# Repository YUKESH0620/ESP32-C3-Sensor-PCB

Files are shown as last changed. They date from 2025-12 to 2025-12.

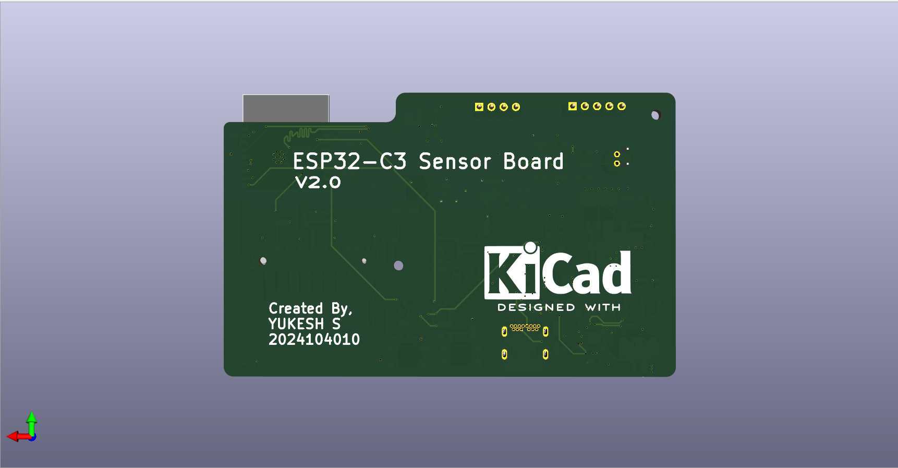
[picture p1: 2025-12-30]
hardware_v0.2_Improved/Kicad_files_v0.2/images_v0.2/PCB_v0.2/Screenshot 2025-12-28 120142.png

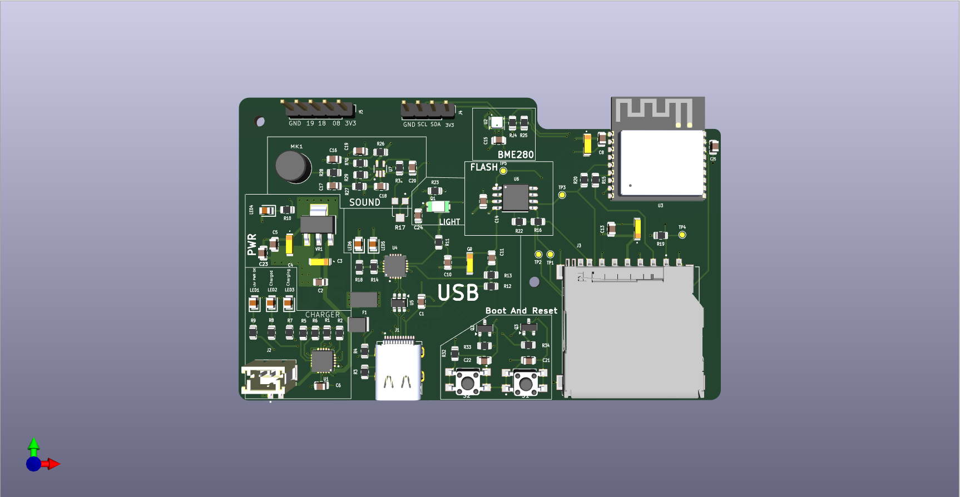
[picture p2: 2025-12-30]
hardware_v0.2_Improved/Kicad_files_v0.2/images_v0.2/PCB_v0.2/Screenshot 2025-12-28 115352.png

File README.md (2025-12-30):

# ESP32-C3 Smart Sensor Board

This repository contains the complete **hardware design** of a custom **ESP32-C3 based Smart Sensor Board**, including schematics, PCB layout, and documentation.

The design integrates **robust power management, multiple sensors, data storage, USB connectivity, and auto-programming**, making it suitable for **IoT, data logging, and embedded systems development**.

---

##  Board Images

###  Complete Schematic








###  PCB Layout


###  3D Views






---

##  System Architecture

### Functional Block Diagram
```text
USB-C / Li-Po Battery
│
MCP73831 Charger
│
+5V Rail
│
LM1117-3.3 LDO
│
+3.3V Rail
│
ESP32-C3 MCU
│ │ │ │
│ │ │ Microphone + MAX4466
│ │ BME280 (I2C)
│ LDR (ADC)
SD Card (SPI)
|
SPI Flash
```
---

##  Key Features

###  Power & Charging
- USB Type-C connector
- Li-Po charging using **MCP73831**
- JST battery connector
- LM1117-3.3 LDO regulator
- Power status LED

###  Microcontroller
- **ESP32-C3-WROOM-02**
- RISC-V core
- Wi-Fi + BLE
- USB-UART programmable

###  Sensors
- **BME280** – Temperature, humidity, pressure
- **Electret microphone + MAX4466 amplifier**
- **LDR photo sensor**

###  Storage
- SPI Flash memory (W25Q32)
- Micro SD card module (SPI)

###  Programming & Debug
- CP2102N USB-to-UART
- Auto-programming (DTR/RTS → EN/BOOT)
- Boot & Reset buttons
- Test points

---

##  Working Principle

### Power Section
- USB-C provides 5V
- MCP73831 safely charges Li-Po battery
- LM1117 converts 5V to regulated 3.3V
- Decoupling capacitors ensure stable rails

### MCU & Sensors
- ESP32-C3 communicates with:
  - BME280 via I²C
  - SD card & Flash via SPI
  - Microphone and LDR via ADC
- Data can be logged or transmitted wirelessly

### Programming
- USB-C → CP2102N
- DTR/RTS control BOOT & EN automatically
- Compatible with ESP-IDF and Arduino

---

## 🧾 Bill of Materials (Detailed – With Values)

###  Active Components

| Ref | Component | Value / Part |
|----|---|---|
| U1 | ESP32 MCU | ESP32-C3-WROOM-02 |
| U2 | Env Sensor | BME280 |
| U3 | USB-UART | CP2102N |
| U4 | Charger IC | MCP73831 |
| U5 | LDO Regulator | LM1117-3.3 |
| U6 | SPI Flash | W25Q32 |
| U7 | Mic Amplifier | MAX4466 |
| J1 | USB Connector | USB Type-C |
| J2 | Battery Connector | JST-PH-2 |
| J3 | SD Card Socket | SPI SD |

---

###  Resistors (From Schematic)

| Ref | Value | Purpose |
|----|---|---|
| R1 | 10kΩ | MCP73831 PROG |
| R2 | 10kΩ | MCP73831 PROG |
| R3 | 5.1kΩ | USB-C CC pull-down |
| R4 | 5.1kΩ | USB-C CC pull-down |
| R5 | 2kΩ | MCP73831 status |
| R6 | 20kΩ | MCP73831 status |
| R7 | 470Ω | Charging LED |
| R8 | 470Ω | Charged LED |
| R9 | 470Ω | Fault LED |
| R10 | 470Ω | Power LED |
| R11 | 1kΩ | USB VBUS link |
| R12 | 22.1kΩ | USB detection |
| R13 | 47.5kΩ | USB detection |
| R15 | 47k | Biasing resistor |
| R23 | 10kΩ | LDR voltage divider |
| R24 | 4.7kΩ | I²C pull-up |
| R25 | 4.7kΩ | I²C pull-up |
| R26 | 2kΩ | Mic bias |
| R27 | 1MΩ | Mic amp gain |
| R28 | 2kΩ | Mic bias |
| R29 | 1MΩ | Mic amp gain |
| R30 | 10kΩ | Mic amp |
| R31 | 2.2kΩ | Mic feedback |
| R32 | 10kΩ | Reset pull-up |
| R33 | 10kΩ | DTR control |
| R34 | 10kΩ | RTS control |

---

###  Capacitors (From Schematic)

| Ref | Value | Purpose |
|----|---|---|
| C1 | 0.1µF | USB decoupling |
| C2 | 0.1µF | LDO input |
| C3 | 10µF | LDO bulk |
| C4 | 10µF | LDO output |
| C5 | 0.1µF | LDO output |
| C6 | 1µF | MCP73831 |
| C7 | 10µF | ESP32 supply |
| C8 | 0.1µF | ESP32 decoupling |
| C10 | 0.1µF | Sensor decoupling |
| C14 | 0.1µF | Flash decoupling |
| C15 | 0.1µF | BME280 |
| C17 | 10nF | Mic coupling |
| C18 | 0.1µF | Mic supply |
| C19 | 1µF | Mic amp |
| C20 | 0.1µF | Mic feedback |
| C21 | 0.1µF | BOOT debounce |
| C22 | 1µF | RESET debounce |

---

##  Design Considerations

- Ground plane for EMI reduction
- ESP32 antenna keep-out respected
- Separate analog routing for microphone
- Decoupling capacitors close to ICs
- USB-C CC resistors correctly implemented
- Battery charging current set safely

---

##  Testing Strategy

- Power rail validation
- USB enumeration
- Battery charge & termination test
- Sensor I²C/SPI verification
- SD card read/write
- ADC noise testing (mic & LDR)

---
##  Revision History

### Rev-A (Initial Prototype)
- ESP32-C3 based sensor board
- Microphone connected to GPIO5 (ADC conflict with Wi-Fi)
- Fixed-gain microphone amplifier
- Photosensor output taken from incorrect pin
- No additional EMI filtering on power path

### Rev-B (Improved Design – Current)
- Resolved ADC conflict between Wi-Fi and microphone
- Improved analog signal quality
- Added EMI noise suppression
- Improved user interface and usability
---

##  Key Engineering Fixes & Improvements

ESP32 PCB prototype 2 improvements and fixes

### 1. ADC Conflict Resolution (Wi-Fi vs Microphone)
- Issue identified during testing: GPIO5 ADC unavailable when Wi-Fi is active
- Root cause: ADC resource conflict on ESP32-C3
- Solution:
  - Microphone OUT moved from GPIO5 → GPIO0 (ADC1)
  - CS_SD reassigned to GPIO5 as digital output
- Result: Microphone and Wi-Fi now operate simultaneously without conflict

### 2. Variable Gain Microphone Amplifier
- Replaced fixed gain network with trimmer potentiometer
- Gain range adjustable from **25× to 125×**
- Improves adaptability for different acoustic environments

### 3. Photosensor Signal Correction
- Output pin corrected from pin 3 → pin 1 as per datasheet
- Added RC filtering capacitors for noise reduction
- Result: Stable and accurate ADC readings

### 4. Analog Noise Reduction
- Added local decoupling capacitor near GPIO0 (MIC_OUT)
- Reduced high-frequency noise on ADC line

### 5. Improved User Interface
- Replaced small tact switches with larger buttons
- Better usability and reliability

### 6. Power Integrity Enhancement
- Added ferrite bead on charger output
- Purpose:
  - Suppress high-frequency switching noise from MCP73871
  - Reduce EMI affecting analog and RF sections

---
##  Design Status

- Rev-A: Initial schematic completed and reviewed
- Design improvements identified during schematic review
- Rev-B incorporates recommended fixes and optimizations
- Hardware fabrication and testing are pending

Note: Functional validation will be performed after PCB fabrication.

---
##  Validation Plan (Post-Fabrication)

- Verify Wi-Fi and microphone operation simultaneously
- Validate ADC stability for photosensor input
- Measure microphone gain range
- Check power rail noise and EMI behavior
- Confirm battery charging and boost operation

---

##  Applications

- Environmental monitoring
- IoT data logger
- Smart sensor node
- Academic & portfolio project
- Embedded systems experimentation

---

##  Future Enhancements

- Fuel gauge IC
- Enclosure design
- OTA firmware support
- EMI compliance testing
- Low-power optimization

---

## 👤 Author

**Yukesh S**  
Embedded Systems Enthusiast  

---

## 📜 License

This project is licensed under the MIT License.

You are free to use, modify, distribute, and commercialize this design,
provided that the original copyright notice and license text are included.

See the [LICENSE](LICENSE) file for full details.

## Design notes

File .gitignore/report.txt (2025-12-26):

Plotted to 'C:\KiCad\ESP-32_C3_Sensor_Board004\ESP-32 C3 demo project004-F_Cu.gbr'.
Plotted to 'C:\KiCad\ESP-32_C3_Sensor_Board004\ESP-32 C3 demo project004-In1_Cu.gbr'.
Plotted to 'C:\KiCad\ESP-32_C3_Sensor_Board004\ESP-32 C3 demo project004-In2_Cu.gbr'.
Plotted to 'C:\KiCad\ESP-32_C3_Sensor_Board004\ESP-32 C3 demo project004-B_Cu.gbr'.
Plotted to 'C:\KiCad\ESP-32_C3_Sensor_Board004\ESP-32 C3 demo project004-F_Paste.gbr'.
Plotted to 'C:\KiCad\ESP-32_C3_Sensor_Board004\ESP-32 C3 demo project004-B_Paste.gbr'.
Plotted to 'C:\KiCad\ESP-32_C3_Sensor_Board004\ESP-32 C3 demo project004-F_Silkscreen.gbr'.
Plotted to 'C:\KiCad\ESP-32_C3_Sensor_Board004\ESP-32 C3 demo project004-B_Silkscreen.gbr'.
Plotted to 'C:\KiCad\ESP-32_C3_Sensor_Board004\ESP-32 C3 demo project004-F_Mask.gbr'.
Plotted to 'C:\KiCad\ESP-32_C3_Sensor_Board004\ESP-32 C3 demo project004-B_Mask.gbr'.
Plotted to 'C:\KiCad\ESP-32_C3_Sensor_Board004\ESP-32 C3 demo project004-Edge_Cuts.gbr'.
Created Gerber job file 'C:\KiCad\ESP-32_C3_Sensor_Board004\ESP-32 C3 demo project004-job.gbrjob'.
Info: Done.
Info: Done.

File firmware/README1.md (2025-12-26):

Firmware is currently under development.
Planned features:
- ESP32-C3 peripheral initialization
- I2C driver for BME280
- ADC reading for LDR & Microphone
- SPI driver for SD card
- Low-power modes (deep sleep)

This repository currently focuses on hardware design and system architecture.

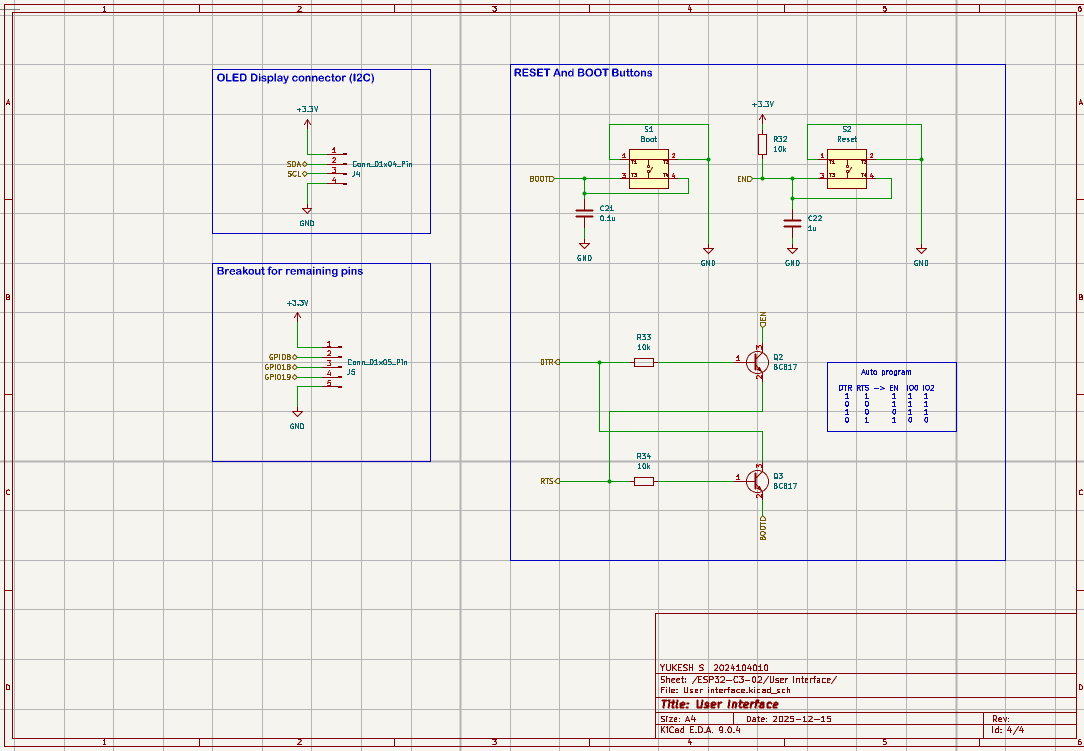
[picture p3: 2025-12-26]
images/Schematic_images/Screenshot 2025-12-26 085659.png

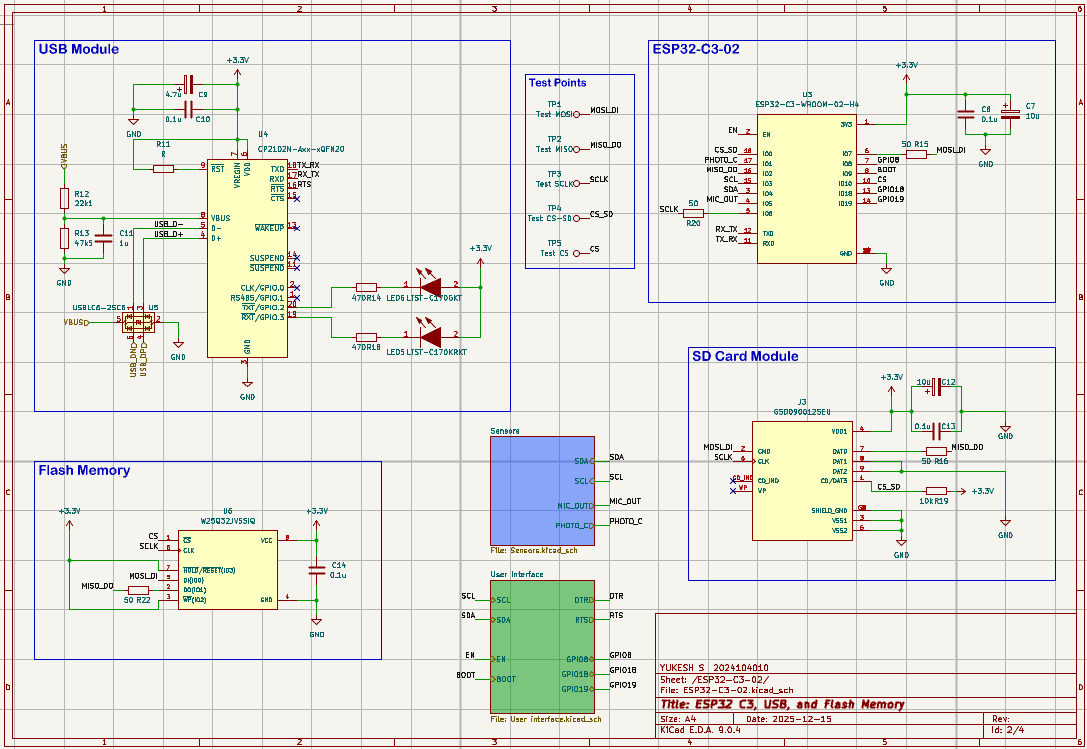
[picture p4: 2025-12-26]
images/Schematic_images/Screenshot 2025-12-26 085602.png

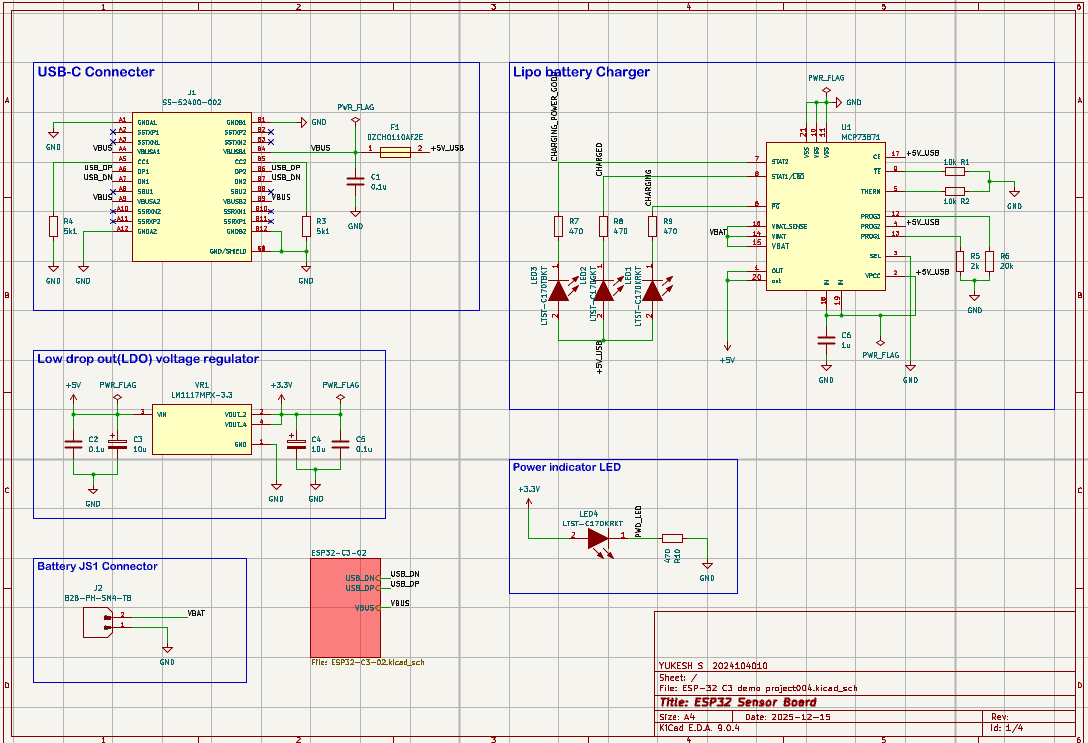
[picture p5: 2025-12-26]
images/Schematic_images/Screenshot 2025-12-26 085358.png

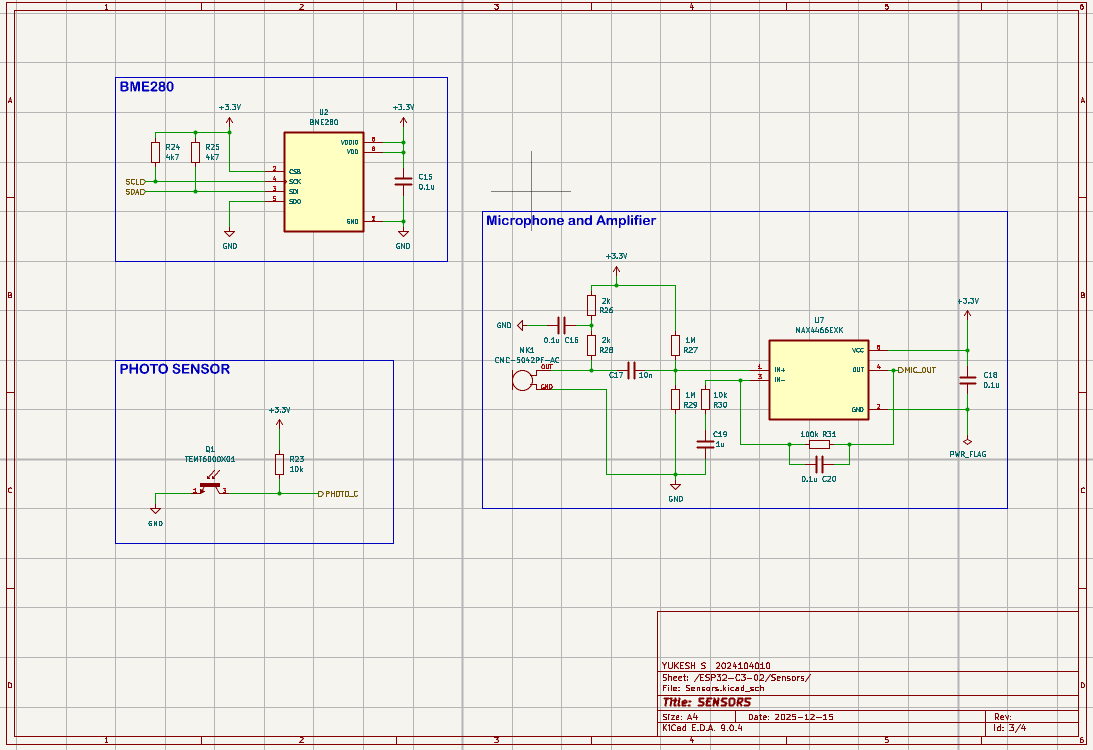
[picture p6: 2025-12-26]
images/Schematic_images/Screenshot 2025-12-26 085631.png

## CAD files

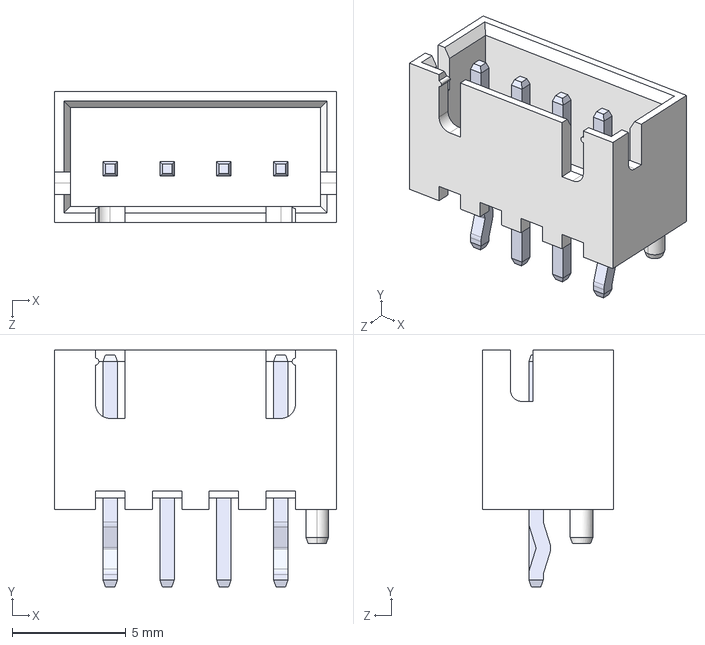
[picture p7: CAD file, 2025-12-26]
docs/External_Design_Blocks/B4B-XH-AM__LF__SN_.step
12.4 x 10.4 x 5.75 mm

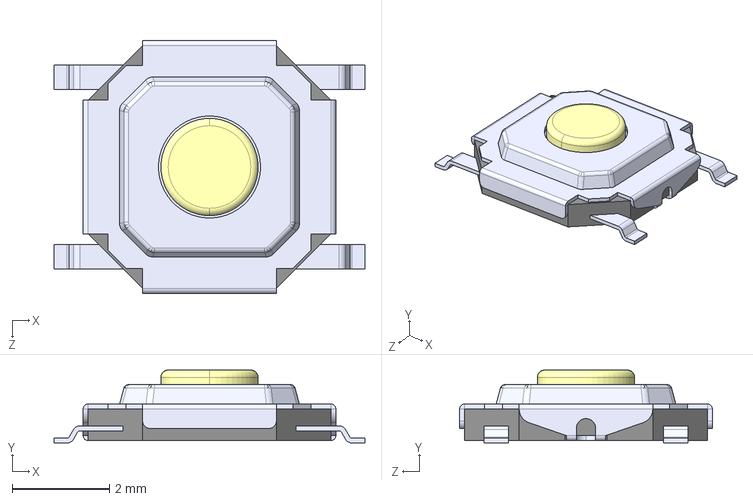
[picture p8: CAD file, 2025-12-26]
docs/External_Design_Blocks/SMD-BUTTON_4P-5.2X5.2X1.5MM-SKQGADE010_.step
6.40 x 1.50 x 5.20 mm

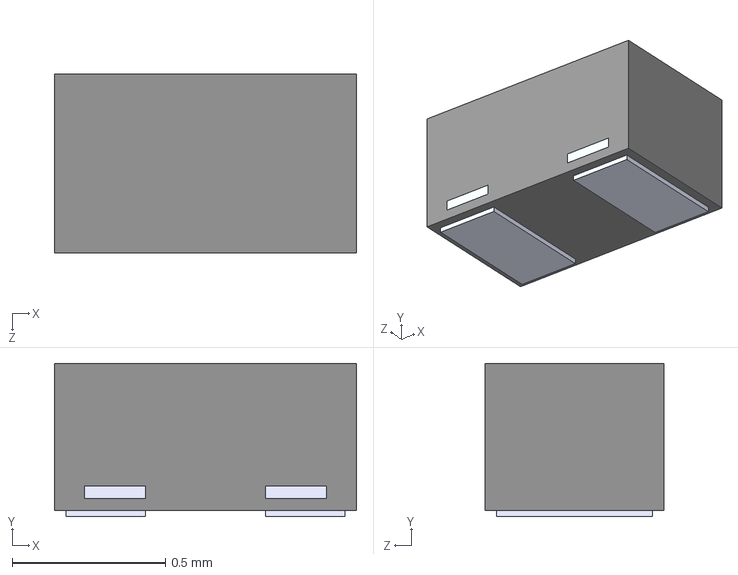
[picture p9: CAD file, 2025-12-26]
docs/External_Design_Blocks/PESD5V0S1UL_315.step
0.985 x 0.5 x 0.585 mm

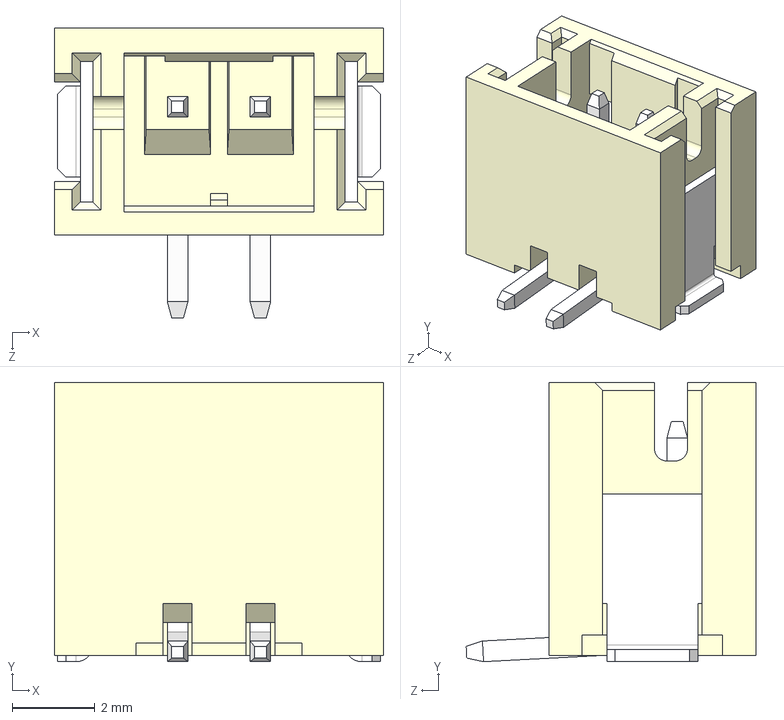
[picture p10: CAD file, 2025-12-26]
docs/External_Design_Blocks/B2B-PH-SM4-TB.step
7.95 x 6.75 x 7.00 mm

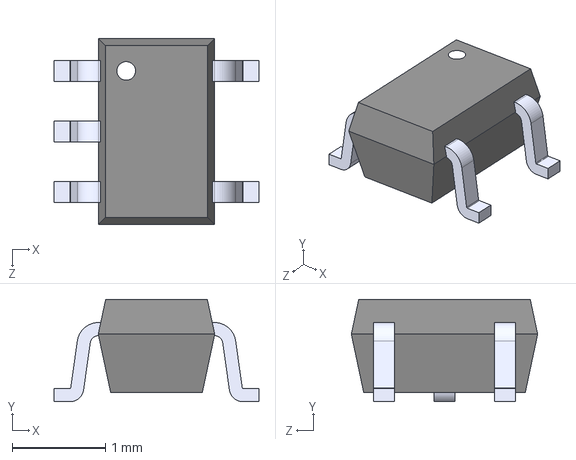
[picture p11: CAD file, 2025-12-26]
docs/External_Design_Blocks/MAX4466EXK.step
2.20 x 1.10 x 2.00 mm

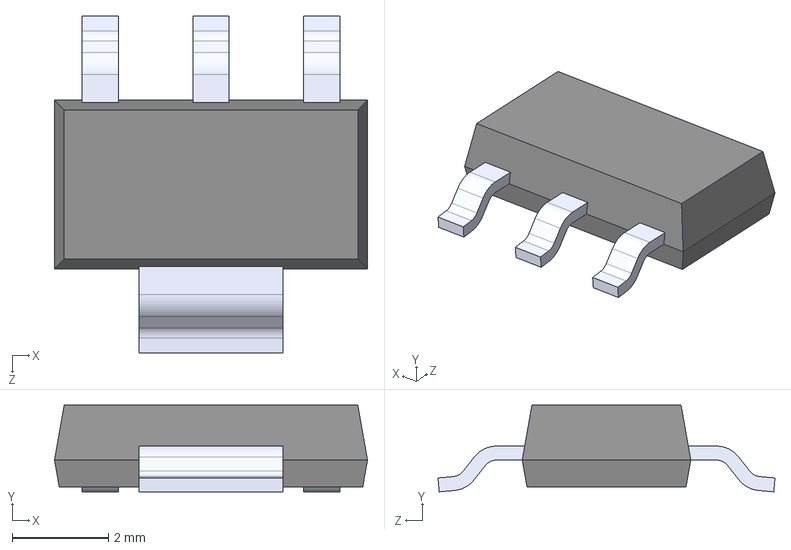
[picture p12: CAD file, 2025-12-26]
docs/External_Design_Blocks/LM1117MPX-3.3_NOPB.step
6.50 x 1.80 x 7.00 mm

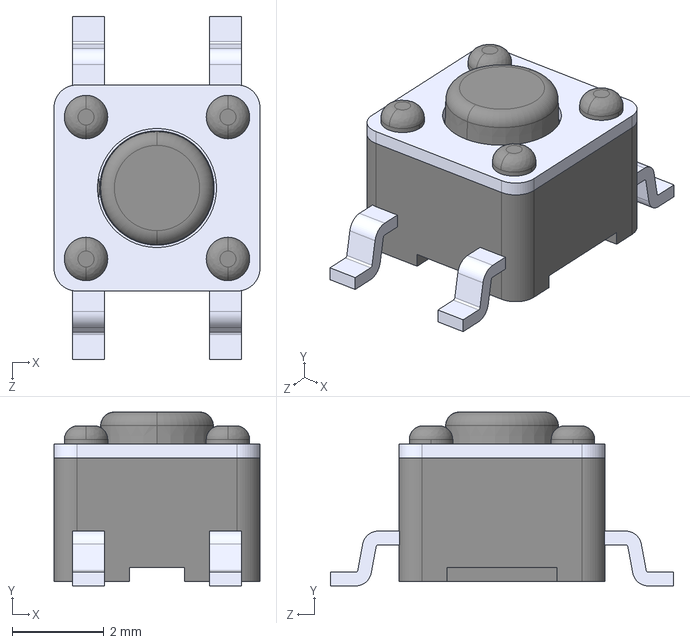
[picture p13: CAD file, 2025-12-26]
docs/External_Design_Blocks/TL3305AF260QG.step
4.50 x 3.80 x 7.50 mm

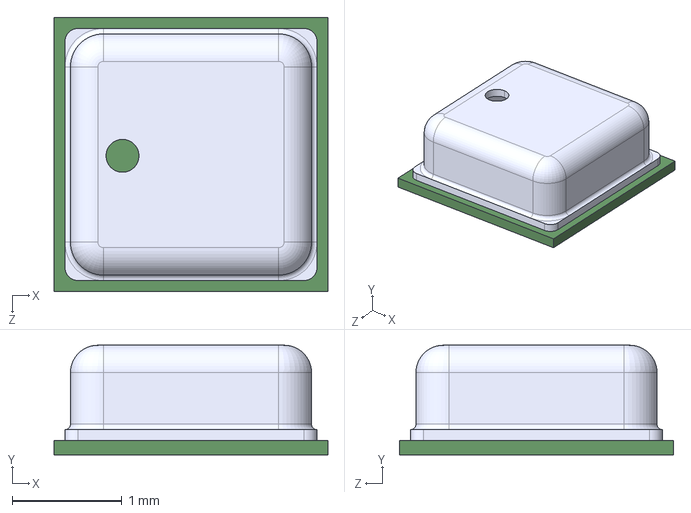
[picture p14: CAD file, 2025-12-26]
docs/External_Design_Blocks/BME280.step
2.50 x 1.00 x 2.50 mm

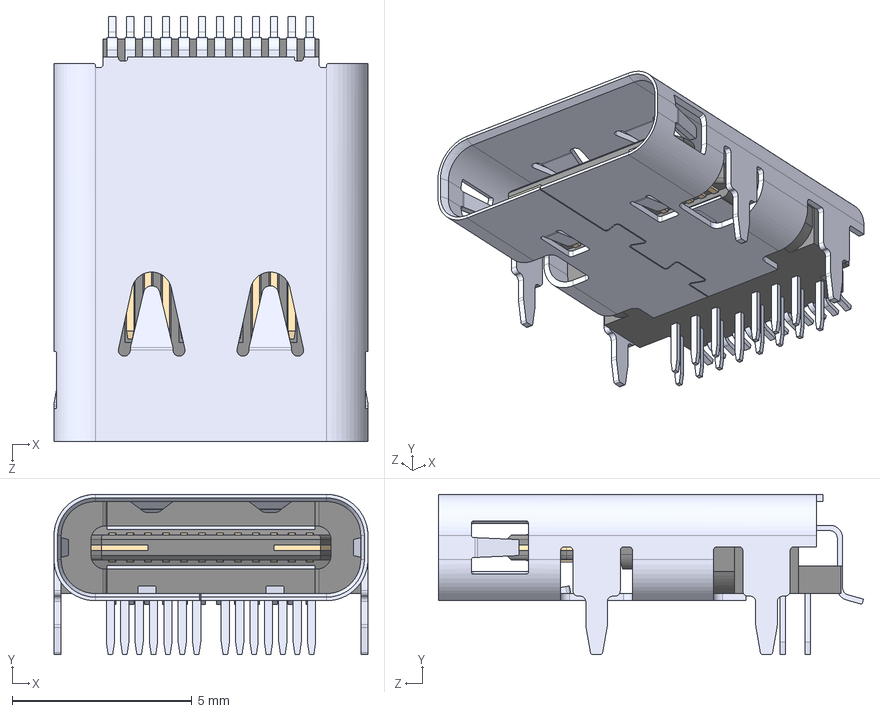
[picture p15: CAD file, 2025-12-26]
docs/External_Design_Blocks/SS-52400-002.step
8.74 x 4.46 x 11.8 mm

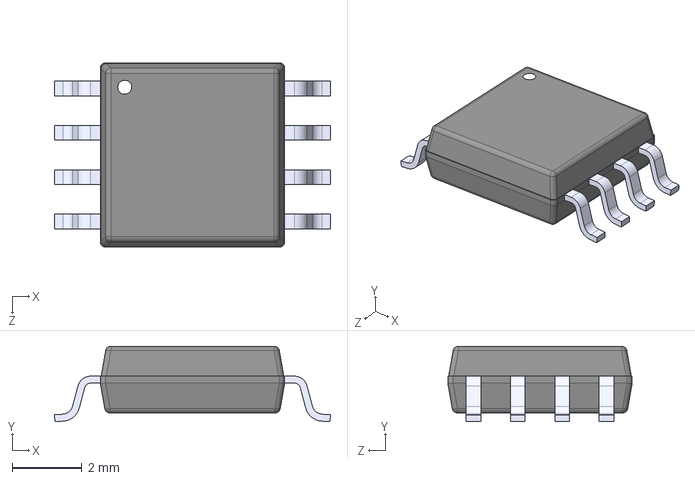
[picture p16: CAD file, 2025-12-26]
docs/External_Design_Blocks/W25Q32JVSSIQ.step
7.90 x 2.16 x 5.28 mm

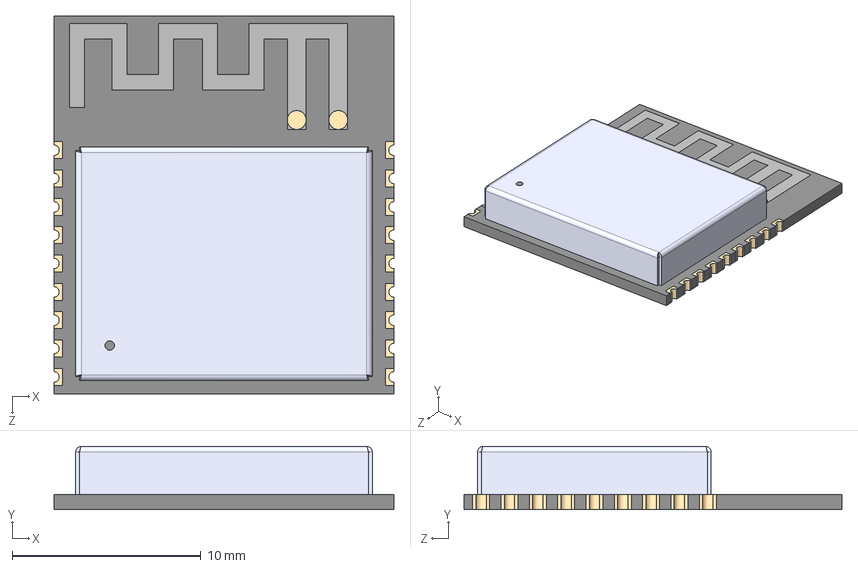
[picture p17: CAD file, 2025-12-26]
docs/External_Design_Blocks/ESP32-C3-WROOM-02-H4.step
18.0 x 3.35 x 20.0 mm

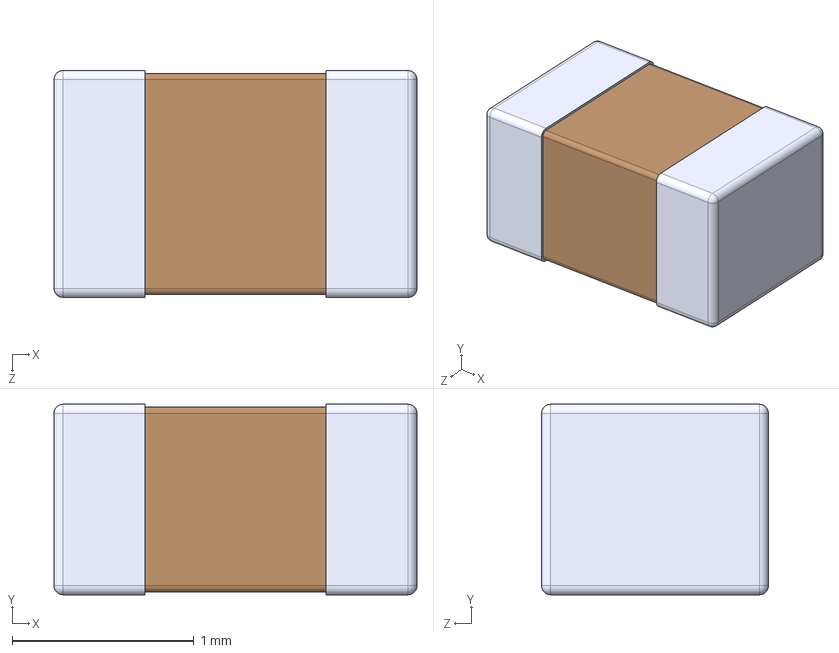
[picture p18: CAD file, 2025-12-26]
docs/External_Design_Blocks/FBMJ2125HM330-T.step
2.00 x 1.05 x 1.25 mm

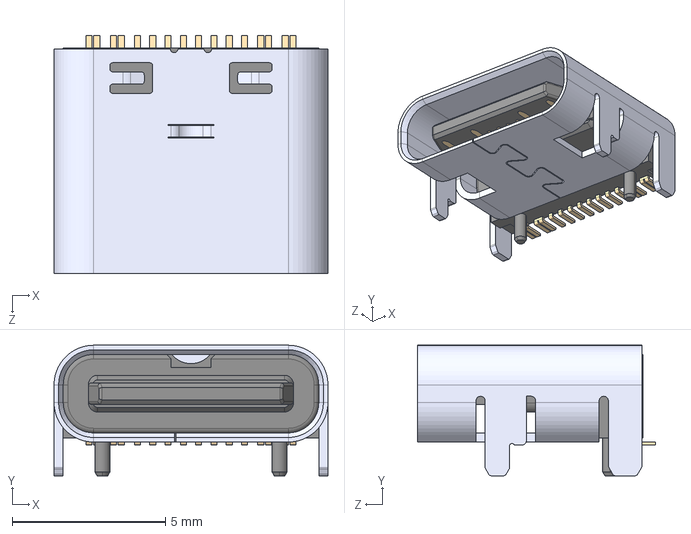
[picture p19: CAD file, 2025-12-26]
docs/External_Design_Blocks/CSP-USC16-TR.step
8.94 x 4.26 x 7.75 mm

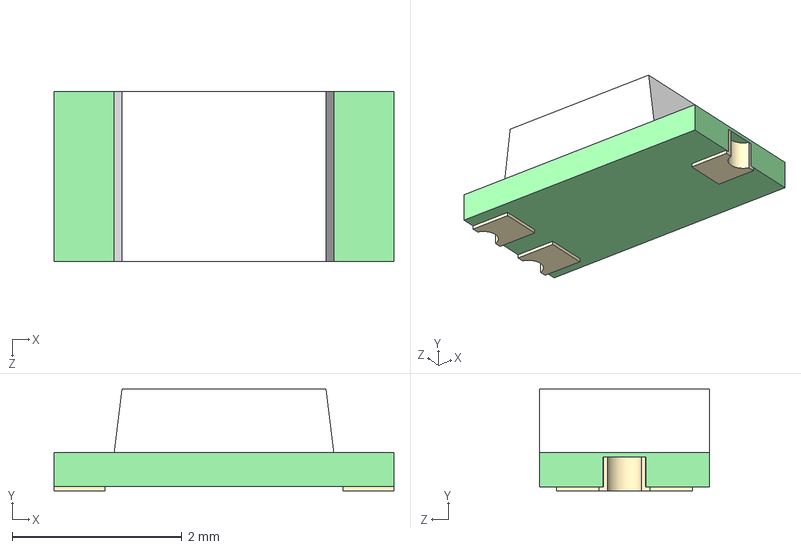
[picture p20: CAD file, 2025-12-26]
docs/External_Design_Blocks/TEMT6000X01.step
4.00 x 1.20 x 2.00 mm

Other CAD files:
docs/External_Design_Blocks/LM1117MPX-3.3.step
docs/External_Design_Blocks/USLPT2819DT2TR.step
docs/External_Design_Blocks/TP4056.step
docs/External_Design_Blocks/USB4110GFA.step
docs/External_Design_Blocks/1-2295018-2.step
docs/External_Design_Blocks/GSD090012SEU.step
docs/External_Design_Blocks/MCP73871-2CAI_ML.step
